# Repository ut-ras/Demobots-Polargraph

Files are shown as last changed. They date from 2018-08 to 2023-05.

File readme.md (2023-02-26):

# Demobots Polargraph
Polargraph GIF

Automated art robot originally built by the 2018-2019 Demobots committee, Revived and Documented by Jake (Demobots) in Spring of 2023

Polargraph translates digital art to a larger, more tangible medium. 

# Table of contents
  - [Demonstration Instructions](#demonstration-instructions)
  - [Updates](#update---feb-26th-2023)
  - [Installation](#installation-via-arduino-ide)
  - [Software](#software)
  - [Electrical](#electrical)
  - [Current Contributors](#current-contributors)

## Demonstration Instructions
### [For current demonstration instructions, click here!](Demos/readme.md)

## Update - Feb 26th, 2023 

- 2023 revival release can be found [here!](https://github.com/ut-ras/Demobots-Polargraph/releases)
- We now have a whiteboard attached to polargraph for easier demos.
- There are now very comprehensive demo instructions, see above.
- There should now be *way* more documentation throughout as well. 

## Installation Via Arduino IDE

1. Download and install the latest version of the Arduino IDE from the official website. Install the [AccelStepper](https://www.airspayce.com/mikem/arduino/AccelStepper/index.html) library via the Arduino IDE Library Manager.

2. Grab the latest release of Polargraph's code and documentation from [here](https://github.com/ut-ras/Demobots-Polargraph/releases) or clone the repo.

3. Open the Arduino IDE, click on File > Preferences, and in the "Additional Boards Manager URLs" field, add this URL: 

```https://dl.espressif.com/dl/package_esp32_index.json```

4. Go to Tools > Board > Boards Manager, search for "ESP32", and install the "ESP32 by Espressif Systems" board.

5. Connect the ESP32 board to your computer via USB.

6. Go to Tools > Board and select "ESP32 Dev Module" from the dropdown menu.

7. Select the appropriate port by going to Tools > Port and choosing the port that your ESP32 board is connected to.

8. Locate the `PolargraphESP32` folder from the release, and open `PolargraphESP32.ino` in Arduino IDE.

9. Click > Upload, and wait for the code to compile.

10. After it compiles, quickly move to ESP32 Board and hold down the `BOOT` button. Hold it down until you see on the IDE that uploading has begun.

11. Wait for the upload to complete, and then install the ESP32-PICO-KIT into Polargraph, and draw away!

## Software

(Both require the [AccelStepper](https://www.airspayce.com/mikem/arduino/AccelStepper/index.html) library)

### [PolargraphESP32](PolargraphESP32) (In use, not maintained)
Runs on an ESP32 in FreeRTOS. Hosts a web server and control interface on the device, and can either connect to an access point or deploy one. Allows users to upload SVG drawing for robot to draw.

### {DEPRECATED} PolargraphArduinoGIOT 
The deprecated PolargraphArduinoGIOT version is included [here](DEPRECATED_FILES/PolargraphArduinoGIOT), but hasn't been touched since 2019, feel free to look into it. 
Runs on an ESP8266. Uses Google Cloud IOT device manager for communication, and connects to an AppEngine web server in polargraph_appengine.

## Electrical
 * [ESP32-PICO-KIT V4 / V4.1](https://docs.espressif.com/projects/esp-idf/en/latest/esp32/hw-reference/esp32/get-started-pico-kit.html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)
 * 2x [NEMA 17 2A Stepper Motors](https://www.amazon.com/Stepper-Bipolar-4-lead-Connector-Printer/dp/B00PNEQKC0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)
 * 2x [A4988 Pololu Stepper Drivers](https://www.pololu.com/product/1182)
 * [5V, 5A Step-Down Voltage Regulator D24V50F5](https://www.pololu.com/product/2851)
 * 12V, 24-36W DC Power Supply
 * 100uF, 50V Capacitor
 * Breadboard with Jumpers

### Circuit Diagram 

Still need to put one here...
*WIP*

### Breadboard Diagram
Note that the MS1 and MS2 pins of each A4988 Stepper Driver are both 5V high, this sets the stepper motors to eighth step, refer to the [A4988 pinout](Electrical/A4988_pinout.png) as needed.

The exact order of the stepper driver output wires depends on the stepper motor used, refer to the [A4988 pinout](Electrical/A4988_pinout.png) as needed.
</br>

![connections](Electrical/breadboard_diagram.png)

*An ESP32-PICO-KIT Fritzing part doesn't exist as of writing, the other ESP32 board was used just to illustrate the pin connections.*

## Current Contributors
 - Jacob Tomczeszyn (Demobots Head) (4jakers18 on the RAS Discord server)

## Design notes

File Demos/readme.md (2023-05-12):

# Instructions for Demos
This guide will hopefully be able to cover everything you'd need to know for demos and SVG files, and will be updated as the project changes. Still, if you encounter any issues, don't hesitate to reach out to me on discord!
 
   -- *Jake (Demobots Head)* 

 - [Setup and Inspection](#setup-and-inspection)
   - [Breadboard Diagram](#breadboard-diagram)
   - [Optional - Changing Out Paper](#optional---changing-out-paper)
 - [Connecting](#connecting)
   - [SSID/password](#connect-to-the-esp32s-access-point-using)
 - [Drawing](#drawing)
   - [Points](#points)
   - [Vector Drawings](#uploading-vector-files-drawings)
 - [SVG Files](#svg-files)
   - [Working SVG Files](#working-svg-files)

## Setup and Inspection
In it's current state, Polargraph is a little heavy and very unwieldy and cumbersome to move around, so be careful and ask for help if you need it. Be sure to grab it's wooden laser-cut stand (better one coming in the future) from the RAS Office as well.

After you've propped it up securely, verify that the winches (black wheels attached the motors) don't have any of their tension string tangled around them. Unravel the power supply cord from Polargraph and set aside. 

Unscrew the backplate of the electrical harness to access the breadboard. (It may be off already)

**Verify that there are no loose connections and that** **everything is seated properly in the breadboard(s).** 

**When doing this, refer to the circuit diagrams, breadboard diagram, pinouts, etc.**

### Breadboard Diagram
Note that the MS1 and MS2 pins of each A4988 Stepper Driver are both 5V high, this sets the stepper motors to eighth step, refer to the [A4988 pinout](../Electrical/A4988_pinout.png) as needed.

The exact order of the stepper driver output wires depends on the stepper motor used, refer to the [A4988 pinout](../Electrical/A4988_pinout.png) as needed.
</br>

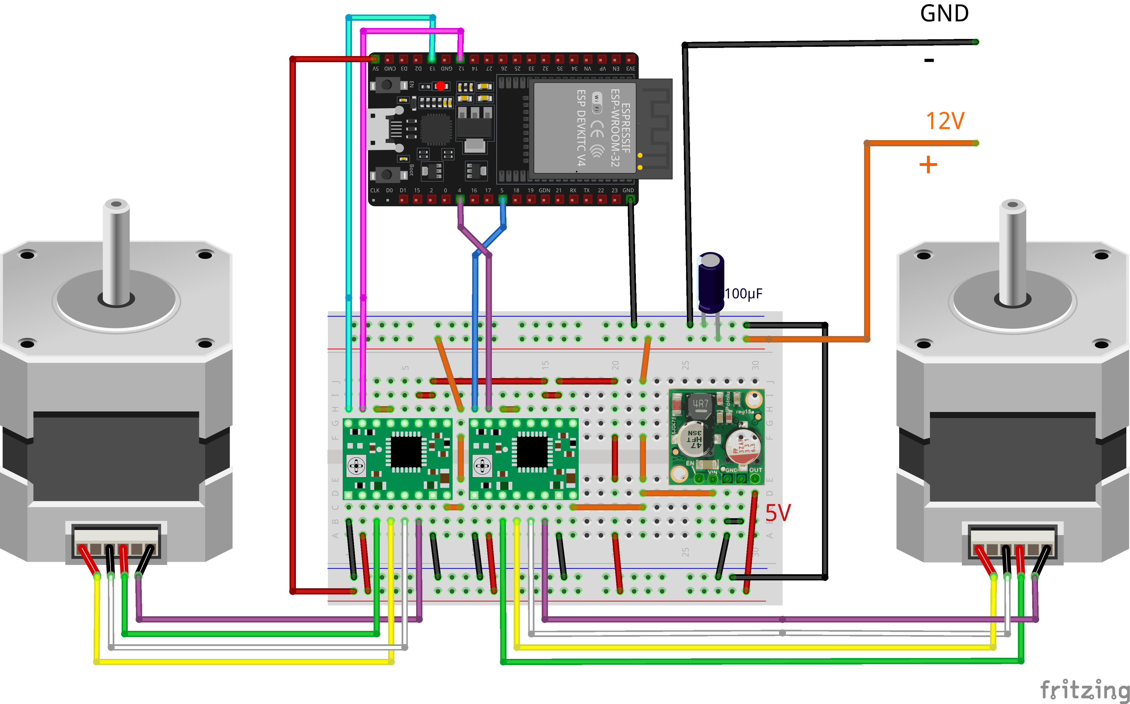
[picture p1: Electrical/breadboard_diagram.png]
connections


*Extra documentation can be found in [Electrical](../Electrical).*

Once you've double checked the connections, you can either rescrew the backplate or leave it open. Go ahead and plug in the power adapter to an AC wall outlet or extension cord.

You'll notice the ESP32's red light come on, along with a quiet but noticable noise coming from the stepper motors, if you don't, something is wrong. Unhook the tension wire from the paper clips and the top of the board, the motors should be locked, holding the gondola (marker holder) in place.

 *(Notice that when the Polargraph loses power, the steppers go limp and drop the gondola, we avoid that by placing the string of each winch hooked on the paper clip its next to.)*

 ## Optional - Changing Out Paper 
Get a piece/roll of large paper and cut it to your desired size, and either attach it to the board using the paperclips already on there, or by using tape. be sure to account for clearence with the winches when sizing your paper.

After you've attached the paper, either measure or guestimate the exact center of the page and mark it with a dot using the marker. There are guide arrows on the top and the left of the whiteboard that point to the center of the usable area.

Carefully and slowly, facing the board, manually adjust the winches (careful not to get anything tangled) such that the gondola's marker hole rest directly over the dot you marked. This is where we will tell Polargraph to set as the origin ("zero") of it's coordinate system. Double check that the gondola hole is exactly or as close as possible to the center.

Now place your marker ***(DRY ERASE ONLY)*** in the gondola, and secure it using the breadtie on there. the portion of marker sticking through the hole should be roughly the same length of the diameter of the castors on the gondola, the gondola should be resting on both the marker tip and the castors.

 ## Connecting
 On your device, be sure to have these instructions open/downloaded, as well as any SVG (Vector files) you'll want to upload to Polargraph to draw.

*The current Polargraph code can be finnicky about what SVG's it likes and which it doesn't like, so I've gone ahead and verified/prepared some good demonstration drawings:*

([Click here for working SVG files](#working-svg-files))

On your device's wifi settings, disable any automatic reconnection to the ***utexas*** wifi (or other public access points), this helps to avoid accidental disconnections.

### Connect to the ESP32's access point using:

|SSID| Password |
|--|--|
|Demobot  | demobot1234  |

**When you're connected to Polargraph's access point, you won't have internet access! Be sure to have everything you need before connecting.**

 ### Once connected, in your web browser, go to [192.168.4.1](http://192.168.4.1/)

 ## Drawing

You should see a page that looks like this:

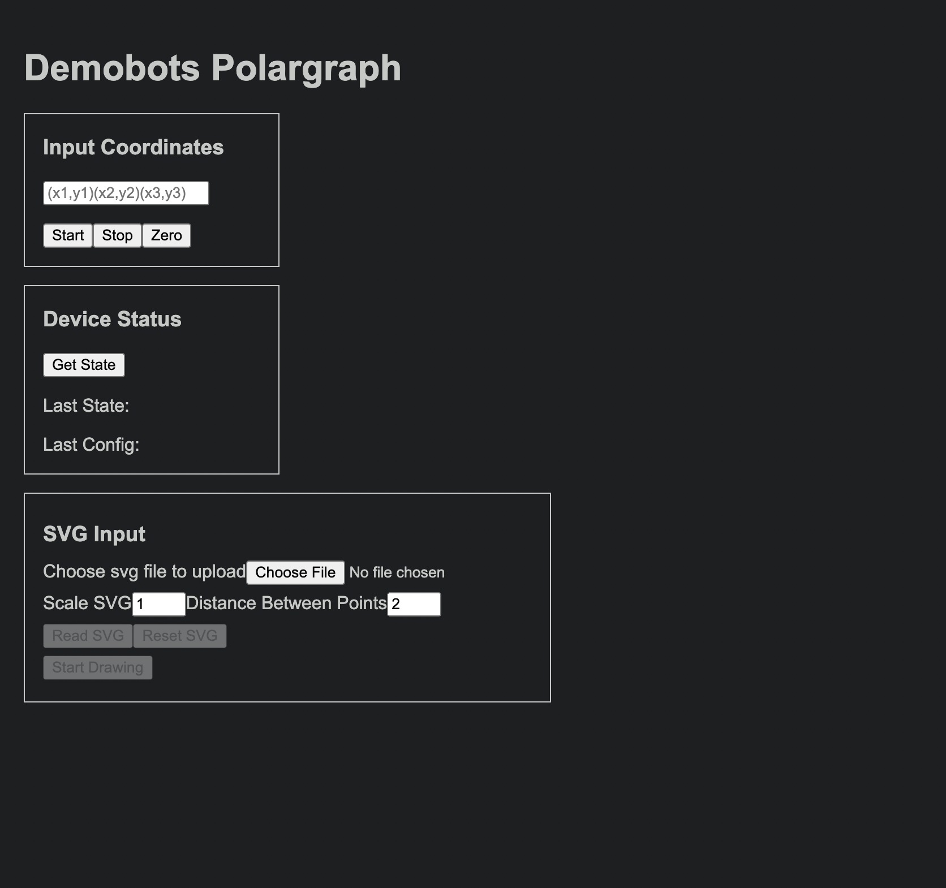
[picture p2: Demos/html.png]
HTML Page


Click on the button marked `Zero` to set the current position as the origin of the graph.

Get a feel for the limits of the board, as the current code is weird and inconsistent. As of 02/25/23, the whiteboard attached is 35" by 24", with a usable area about half an inch less due to the tape. There also appears to be some sort of coded change to the Y-Max set in [polargraph.h](../PolargraphESP32/src/polargraph/polargraph.h) that cuts it down a bit. All four of the limits seem to get cut down by 10mm regardless.

This all translates to the rough limits of:

|X-Max| X-Min |Y-Max| Y-Min |
|--|--|--|--|
| 440 mm  | -440 mm  | (~) 300 mm| -340 mm|

### Points

You can input `(x,y)` coordinates you want the gondola to travel to in the text box at the top.

Press `Start` to start a movement. 

Press `Stop` to pause a movement.

To cancel a movement in progress, you will have to press `Stop` and reboot the ESP32 (Do this via pulling it's `GND` Jumper to avoid the gondola falling).

You can chain together multiple points in sequence like this: `(x1,y1)(x2,y2)(x3,y3)` 

(Remember that drawing straight lines is hard to do manually, as this uses a Bipolar coordinate system for the movement, so it makes arcs when traveling between points.) 

To return to the origin, dont press `Zero`! This isn't a 3D Printer, it doesn't have any position feedback. 
Simply type `(0,0)` into the text box and press `Start`.

### Uploading Vector Files (Drawings)

Before connecting to Polargraph, download the SVG files found [here](SVGs/WORKING).

Click the `Choose File` button on the webpage, and select the SVG file you want to draw.

Scale the SVG if needed [(see below)](#svg-files) in the `Scale SVG` box. This is a multiplier for the default size of the file, numbers greater than `1.0` will increase the size, to decrease the size of the image, input the scale as a decimal less than `1.0`. For example: for a 175% scale, type: `1.75`, for a for a 35% scale, type: `0.35`. (Negative values will flip the drawing, try to avoid that).

Don't worry about the `Distance Between Points` box, changing this number can break things, leave at `2`.

After you've chosen your file and scaled to your heart's desire, click  the `Read` button. 

This loads the drawing path, scroll down to see the preview windows, the top is the SVG, the bottom is the drawing path that Polargraph will take.

Click `Start Drawing` to start drawing! (who would've guessed?)

When you're down with that drawing, or want to have something new on the board, click `Reset SVG` or refresh the page. 

***Don't*** click `Read SVG` while you already have a SVG loaded in. Having more than one at a time can result in bad paths. 

## SVG Files

The vector to movement algohrithm is complicated, and to be honest, I'm not sure which file here actually contains that code...

So I've had to work out the following by trial and error!

- Only certain SVG's will work properly, they have to consist of vector paths only with a thickness of one pixel.
- Don't use any "image to vector" converters online, its best to trace out the path of the drawing you want using Inkscape or a similar program.
- Some of the 'Working' SVG files are still too big/small to be drawn properly in the current configuration. Use them based on the notes below.

### Working SVG Files

SVG's confirmed to work can be found [here](SVGs/WORKING)
________________________________________________________
[longhorn](SVGs/WORKING/longhorn.svg)



- Best SVG we have so far
- Centered on origin well, but the drawing path starts at the tip of the right horn, so there will be an ugly travel line unless you tell it to move to that coordinate and erase the travel line before starting drawing. 
- It is fairly small by default, but not undrawable, you should be able to scale to 5ish at the most, experiment with it.
________________________________________________________
[creeper](SVGs/WORKING/creeper.svg)



- About the same as longhorn.svg in terms of sizing and centering, ugly travel path is smaller.
- ***aww man***
________________________________________________________
[Spiral](SVGs/WORKING/Spiral.svg)


- The centering is off by a lot, the whole spiral is drawn though, but (for some stupid reason I'm sure) the spiral is centered down and to the right when read into Polargraph.
- I wouldn't go above a 2x for this one, its fairly big as is.
________________________________________________________
[running-dog-silhouette](SVGs/WORKING/running-dog-silhouette.svg)



- ***May be too big by default***, I haven't tested it in since implementing the currect conifugrations, play around with it. 
- Gets squished/squashed weird sometimes
________________________________________________________

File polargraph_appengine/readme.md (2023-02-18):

#{Deprecated} Demobots Polargraph IOT
UT Austin's R.A.S. Demobots made an Arduino polargraph on an ESP8266, and this example adds a Google App Engine front end and communication through Cloud IoT Manager's HTTP bridge. </br>
</br>
Cloud IOT provides a simple and secure REST API (cloudiotdevice) for the device to post state and get config to the device manager. The device manager stores some of the most recent states and configs, and another API (cloudiot) can access the device manager. </br>
</br>
Google AppEngine is a platform for building webapps, it hosts webapp and gives you access to diagnostic tools. </br>
</br>
If you deploy the project to appengine instead of running the server locally, pay attention to Cloud's pricing and data quotas, there is a free trial but the credits will run out eventually.

Polargraph Image

## Google Cloud Tutorials
AppEngine Tutorial: Setting up gcloud development environment, python bookshelf app, Flask, Jinja, OAuth, CloudSQL</br>
https://cloud.google.com/python/getting-started/tutorial-app</br>
Cloud IoT How-To's: Config, state, HTTP bridge </br>
https://cloud.google.com/iot/docs/how-tos/getting-started</br>
Cloud IoT REST Reference: APIs for the HTTP device manager (cloudiot) HTTP bridge (cloudiotdevice)</br>
https://cloud.google.com/iot/docs/reference/rest/</br>
Cloud IoT Manager Example: Using python client library to connect to IoT device manager with cloudiot API</br>
https://github.com/GoogleCloudPlatform/python-docs-samples/tree/master/iot/api-client/manager</br>
Cloud IoT Core JWT Arduino library: Cloud IoT end device examples on Arduino, JWT, receiving config, updating state, sending telemetry to PubSub with cloudiotdevice API</br>
https://github.com/GoogleCloudPlatform/google-cloud-iot-arduino</br>

## Arduino Libraries
ESP8266WiFi</br>
Google Cloud IoT Core JWT</br>
AccelStepper</br>
rBase64</br>
QueueList</br>

## Google Cloud Services
Google App Engine (python with Flask, Jinja, SQLAlchemy)</br>
OAuth 2.0 </br>
Cloud SQL </br>
Cloud IoT Manager with HTTP bridge</br>

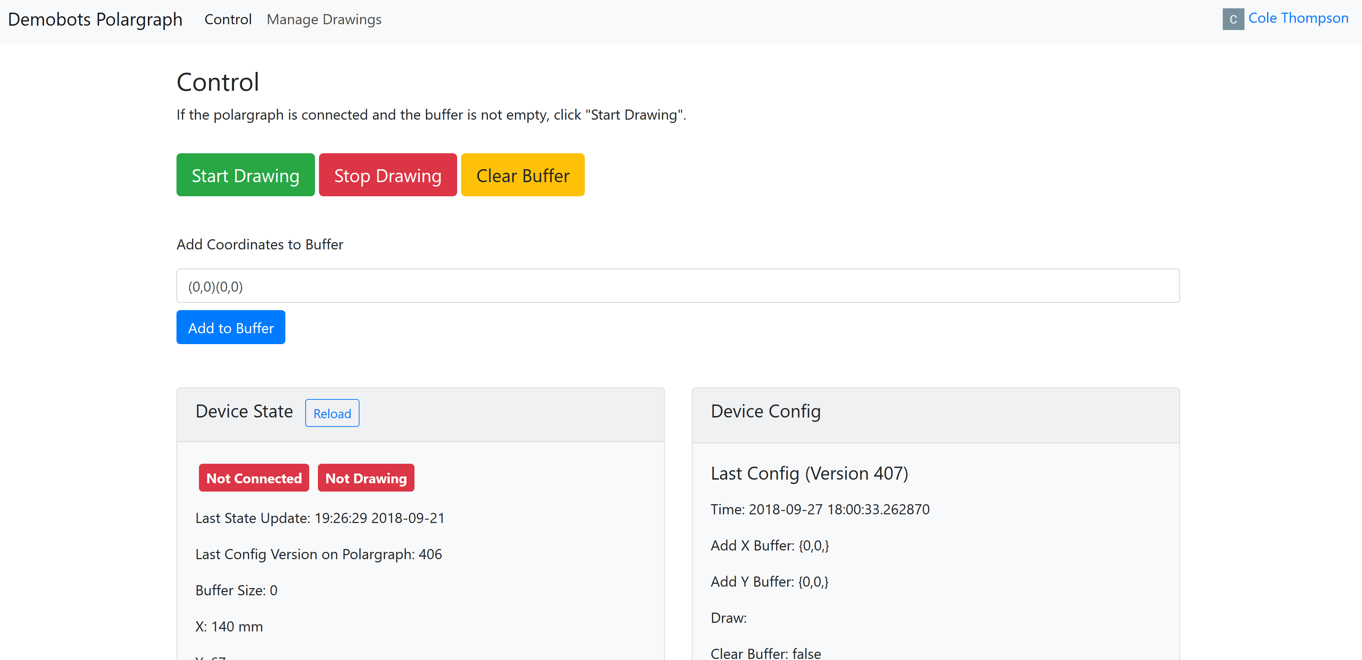
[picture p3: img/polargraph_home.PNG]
Polargraph Webapp Image

</br>
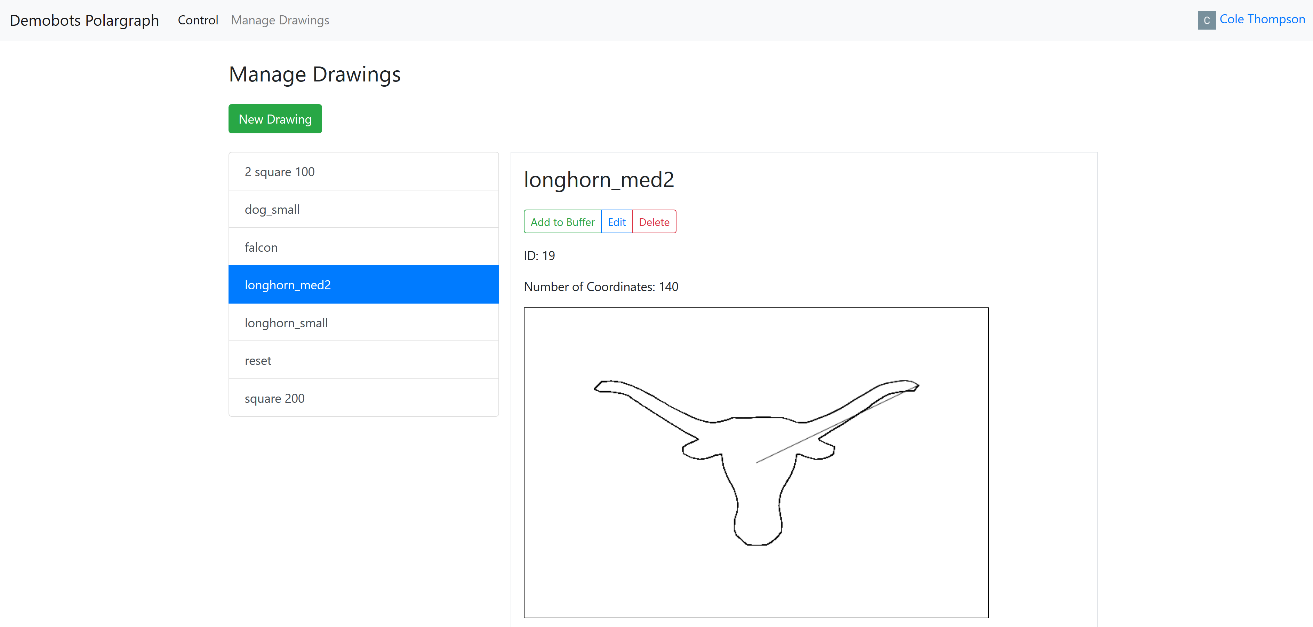
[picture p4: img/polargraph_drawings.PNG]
Polargraph Webapp Image


## Google Cloud Console Stuff to Set Up
Things to do when setting up this project. In general, follow the examples and tutorials.
* Google Cloud Project
* Cloud SQL Instance and drawings Database
* Cloud IOT Registry and Device with EC Public Private Key Pair and Service Account
* Enable all API's - Cloud IoT, AppEngine Flexible, Cloud SQL, CLoud SQL Admin, Google+, (might be more)
* Config files were not committed for security reasons, so make copies of everything with "\_EXAMPLE", remove the "\_EXAMPLE", and fill in your info, read comments for instructions

## Running AppEngine Locally (Linux)
First, make sure that project is set up like in Bookshelf tutorial, Google Cloud SDK is installed, and config.py/app.yaml are set up.</br>
virtualenv -p python3 env</br>
source env/bin/activate</br>
pip install -r requirements.txt</br>
python main.py</br>

## Running Cloud SQL Locally (Linux)
Install Proxy:</br>
wget https://dl.google.com/cloudsql/cloud_sql_proxy.linux.amd64 -O cloud_sql_proxy</br>
chmod +x cloud_sql_proxy</br>
Run Proxy:</br>
./cloud_sql_proxy -instances=project-name:us-central1:sql-name=tcp:3306</br>

## Hardware
 * [ESP8266 ESP 12-E WiFi Development Board](https://www.amazon.com/Makerfocus-ESP8266-ESP-12E-Internet-Development/dp/B01IK9GEQG)
 * 2x [NEMA 17 2A Stepper Motors](https://www.amazon.com/Stepper-Bipolar-4-lead-Connector-Printer/dp/B00PNEQKC0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)
 * 2x [A4988 Pololu Stepper Drivers](https://www.pololu.com/product/1182)

## TODO
Come to Demobots meetings or message R.A.S. if you want to participate! Any ideas are welcome. We are going to set up a more official task system in the future, but for now here are some tasks.

#### Arduino:
* Maybe use an RTOS to multithread
* Serial Mode (takes config as string)
* Minimize size and number of config transmissions for drawings

#### Cloud:
* Maybe using device metadata would be helpful for polargraph size, wifi connection settings, etc
* PubSub could be cool for drawings instead of using config
* Cloud IoT also has an MQTT bridge we can try

#### AppEngine:
* Editable canvas in Add Drawing
* Improve SVG tools to handle multiple paths
* SVG polargraph size text input
* Background thread or task queue when number of coordinates needs multiple configs

#### Hardware:
* New pen holder, possibly with a small servo to lift/place the pen
* Big reset / stop / motor power buttons (use interrupts for stop)
* Surface for drawing with dry erase markers
* Find an appropriate battery pack for outdoor demos

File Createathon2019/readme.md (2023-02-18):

# {Deprecated} Createathon Polargraph 2019
Large drawing machine for Createathon 2019. Includes a wireless device to lift and place the marker. Software based on the [UT Robotics and Automation Society Polargraph](https://github.com/ut-ras/Demobots-Polargraph-IOT/tree/master/PolargraphESP32). </br>

## Hardware
  * Polargraph
      * [ESP32 Pico Kit Microcontroller](https://www.mouser.com/ProductDetail/Espressif-Systems/ESP32-PICO-KIT?qs=MLItCLRbWsyoLrlknFRqcQ%3D%3D)
      * 2x [NEMA 17 2A Stepper Motors](https://www.amazon.com/Stepper-Bipolar-4-lead-Connector-Printer/dp/B00PNEQKC0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)
      * 2x [A4988 Pololu Stepper Drivers](https://www.pololu.com/product/1182)
      * Pololu 5V 5A Voltage Regulator
      * 12V DC input
  * Wireless Marker
      * ESP8266-01 Microcontroller
      * Servo Motor
      * Pololu 3.3V 2A Voltage Regulator
      * 5V rechargeable USB battery

### ESP32 Pins
Stepper | Step | Direction
--- | --- | ---
**R** | GPIO 12 |GPIO 13
**L** | GPIO 4 | GPIO 5

## Source Files

### PolargraphESP32_Async
  * `PolargraphESP32_Async.ino` main file, starts the FreeRTOS threads
  * `src/iot/` contains modules for WiFi and the HTTP Web Server
      * `src/iot/webserver.h` HTTP Web Server
      * `src/iot/webserver.cpp`
      * `src/iot/templates.h` Web Server front end HTML templates
      * `src/iot/iot_config.h` Quick WiFi settings
      * `src/iot/wifi_setup.h` WiFi connection functions
      * `src/iot/json_parse.h` JSON parse functions
  * `src/polargraph/` contains the polargraph device class, motor control, and the coordinate buffer
      * `src/polargraph/polargraph.h`
      * `src/polargraph/polargraph.cpp`
  * `static/` HTML and JS source files used to generate the string literals in the web server templates

### PolargraphMarker
  * `PolargraphMarker.ino` main file
  * `http.h` HTTP Client for Server-Sent Events
  * `http.cpp`
  * `marker.h` Servo code
  * `marker.cpp`

## Arduino Libraries
ESP32-Arduino, FreeRTOS (add the ESP32 to the Arduino board manager, select ESP32 Pico Kit) </br>
ESPAsyncWebServer (add as a zip)</br>
AsyncTCP (add as a zip)</br>
AccelStepper (Arduino library manager)</br>

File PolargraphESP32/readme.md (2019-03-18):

# Demobots Polargraph ESP32
Uses arduino-esp32 FreeRTOS core. Hosts a web server which allows nearby users to control the device when in the same local network. Supports SVG file inputs and lists of coordinates. </br>

Polargraph Image

## Arduino Libraries
ESP32-Arduino, FreeRTOS</br>
AccelStepper</br>

## Source Files
  * `src/iot` contains modules for WiFi and the HTTP Web Server
    * `src/iot/webserver.h` HTTP Web Server
    * `src/iot/webserver.cpp`
    * `src/iot/templates.h` Web Server front end HTML templates
    * `src/iot/iot_config.h` Quick WiFi settings
    * `src/iot/wifi_setup.h` WiFi connection functions
    * `src/iot/json_parse.h` JSON parse functions
  * `src/polargraph` contains the polargraph device class, motor control, and the coordinate buffer
    * `src/polargraph/polargraph.h`
    * `src/polargraph/polargraph.cpp`
  * `static` HTML and JS source files used to generate the string literals in the web server templates

## WiFi Settings
 * WiFi ssid, pass, and mode set in `src/iot/iot_config.h`
 * `WIFI_MODE` Modes:
   * `AP` Access Point: Device Broadcasts an access point, webserver IP default `192.168.4.1`
   * `STA` Station : Device connects to existing access point, webserver IP based on access point settings
   * `AUTO` Auto: Device searches for existing access point, and broadcasts if it can't find one

## Hardware
 * [ESP32 Pico Kit](https://www.mouser.com/ProductDetail/Espressif-Systems/ESP32-PICO-KIT?qs=MLItCLRbWsyoLrlknFRqcQ%3D%3D)
 * 2x [NEMA 17 2A Stepper Motors](https://www.amazon.com/Stepper-Bipolar-4-lead-Connector-Printer/dp/B00PNEQKC0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)
 * 2x [A4988 Pololu Stepper Drivers](https://www.pololu.com/product/1182)

### ESP32 Pins
Stepper | Step | Direction
--- | --- | ---
**R** | GPIO 12 |GPIO 13
**L** | GPIO 4 | GPIO 5

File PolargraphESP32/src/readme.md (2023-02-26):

# Polargraph Source Files
##### ***This readme was made using ChatGPT***

# [polargraph](/polargraph/)
The header file defines some constants: a `pos` struct to represent a position on the polargraph, and some functions to interact with the polargraph.

The constants defined are:

- `X_MAX` and `Y_MAX`: the maximum X and Y coordinates of the drawing area in millimeters.
- `STEP_MULT`: a factor to multiply the number of steps taken by the polargraph motors. This is used to increase the resolution of the polargraph drawing.
- `PULLEY_RADIUS`: the radius of the pulleys used by the polargraph in millimeters.
- `PULLEY_CIRC`: the circumference of the pulleys used by the polargraph in millimeters (calculated from `PULLEY_RADIUS`)
- `STEPS_PER_ROT`: the number of steps the polargraph motors take to complete one rotation.

The `pos` struct contains two 16-bit integers, `x` and `y`, to represent the X and Y coordinates of a position on the polargraph. It also defines an `operator=` function to assign one `pos` struct to another, an `operator==` function to compare two `pos` structs for equality, a `toString` function to convert a `pos` struct to a string, and an `toArray` function to convert a `pos` struct to an array of two 16-bit integers.

The public functions defined by polargraph.h and used in polargraph.cpp are:

- `setupPolargraph`:  This function initializes the polargraph by setting the max speed of each stepper motor, creating a queue to buffer incoming positions, and calculating the length of the strings based on the current position of the marker. It also prints some debug information to the serial console.
- `loopPolargraph`:This function is called repeatedly in the main loop of the program. It checks if the polargraph is currently drawing, and if so, it checks if it has reached the next position yet. If it has reached the position, it retrieves the next position from the queue and sets the polargraph to move to that position. If the queue is empty, it stops the drawing.
- `addToBuffer`: This function adds a new position to the end of the queue. It takes a pointer to a `pos` struct as an argument.
- `clearBuffer`: clears the buffer (clears the queue of positions).
- `getBufferSize`: gets the size of the polargraph buffer.
- `getCurrentPos`: gets the current position of the polargraph.
- `resetPos`: sets the current position of the polargraph as (0, 0) and enables drawing. No actual movement is done here, there are no limit switches or feedback.
- `getLeftLength`: This function calculates the length of the left string required to reach a given position pos_new.
- `getRightLength`: This function calculates the length of the right string required to reach a given position pos_new.
- `setPos`: This function sets the position of the marker to a given position pos_new. It first checks if the position is valid (i.e., within the boundaries of the drawing board). If it is valid, it calculates the new length of the left and right strings required to reach the new position. It then calculates the number of steps required for each motor to reach the new string lengths, and sets the motors to move to those positions. Finally, it updates the internal variables for the current position, string lengths, and number of steps.
- `getDistance`: calculates the distance between two `pos` structs.
- `getIsDrawing`: gets the current drawing state of the polargraph.
- `setIsDrawing`: sets the drawing state of the polargraph.

_________________________

# [iot](/iot/)

## wifi_setup.h

The `setupWiFiAutoScan()`, `setupWiFiAuto(`), and `setupWiFi()` functions are used to initialize the WiFi connection. `setupWiFiAutoScan()` scans for available WiFi networks, and if it finds the desired network, it connects to it as a Station (STA). If it doesn't find the network, it creates an Access Point (AP) and sets the IP address accordingly. `setupWiFiAuto()` does the same thing, but assumes that the WiFi mode is set to "AUTO". Finally, `setupWiFi()` is a more general function that allows the user to specify whether they want to use AP or STA mode.

The file also defines the local_IP, gateway, and subnet IP addresses, which are used to configure the static IP address of the Polargraph machine.
## iot_config.h
This file is a header for wifi_setup.h and defines the WiFi mode (`WIFI_MODE`) and the SSID and password for the WiFi network.

"AP" is currently set for access point mode.

## templates.h
This file contains html templates for [PolargraphESP32/static](../static)

## json.parse.h

This file contains a simple JSON parser.

### Functionality

The `getFromJson` function extracts a value from a JSON string given the attribute name. The function assumes that there are no duplicate names in the JSON string. The function finds values in the format `'attr_name':'val'` and returns `val`. 

The `getFromJson2` function is similar to `getFromJson`, but it returns a default value if the attribute is not found in the JSON string.

The `stringToBool` function converts a string value of either `"true"` or `"false"` to a boolean value.

### Future Improvements

The file contains a comment about potential improvements to the JSON parser. Specifically, the comment suggests using a thread with a char queue input to constantly stream chars from the queue and parse all JSON and coordinates into the polargraph input in one pass, just checking for the delimiters `{`, `:`, etc.

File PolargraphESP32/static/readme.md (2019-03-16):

# Templates

Develop front end pages here, escape the text (search online c++ escape tool) and add to `src/iot/templates.h`

## String Storage Examples
Some of the examples are untested, I'll test them at some point soon to make sure they are syntactically correct. </br>
</br>
Global buffer in SRAM initialized data.
```C++
#define HTML_LITERAL "<html><h1>Hello</h1></html>"
#define HTML_SIZE sizeof(HTML_LITERAL)
const char * html = HTML_LITERAL;
char * helloHTML() {
  return html;
}
```
Static buffer in SRAM initialized data.
```C++
#define HTML_LITERAL "<html><h1>Hello</h1></html>"
#define HTML_SIZE sizeof(HTML_LITERAL)
char * helloHTML() {
  static char * html_str = HTML_LITERAL;
  return html_str;
}
```
Static buffers in SRAM initialized data, using sprintf to add some run-time variables.
```C++
#define HTML_LITERAL "<html><h1>Hello %s</h1></html>"
#define HTML_SIZE sizeof(HTML_LITERAL)
#define BUFFER_SIZE (HTML_SIZE + 50)    //add room for max name length
char * helloHTML(char * name) {
  static char * html_str = HTML_LITERAL;
  static char buffer[BUFFER_SIZE];
  snprintf(buffer, BUFFER_SIZE, html_str, name);
  return buffer;
}
```
Three web pages stored in Flash buffers. If only one client is connecting, only one page needs to be loaded into one global buffer in SRAM data.
```C++
#include <pgmspace.h>
#define BUFFER_SIZE 100
char buffer[BUFFER_SIZE];   //stores 1 page at a time
const char fbuffer1[] PROGMEM = {"<html><h1>Hello 1</h1></html>"};
const char fbuffer2[] PROGMEM = {"<html><h1>Hello 2</h1></html>"};
const char fbuffer3[] PROGMEM = {"<html><h1>Hello 3</h1></html>"};
char * page1HTML() {    //put fbuffer1 in buffer
  int k;
  for (k = 0; k < strlen_P(fbuffer1); k++) {
    strcpy_P(&buffer[k], (char *)pgm_read_byte_near(fbuffer1 + k));
  }
  return buffer;
}
```
Avoid putting large constant strings on the stack or heap. </br>
</br>
https://www.geeksforgeeks.org/memory-layout-of-c-program/</br>
http://playground.arduino.cc/Learning/Memory</br>
https://learn.adafruit.com/memories-of-an-arduino/optimizing-sram</br>
https://www.arduino.cc/reference/en/language/variables/utilities/progmem/</br>

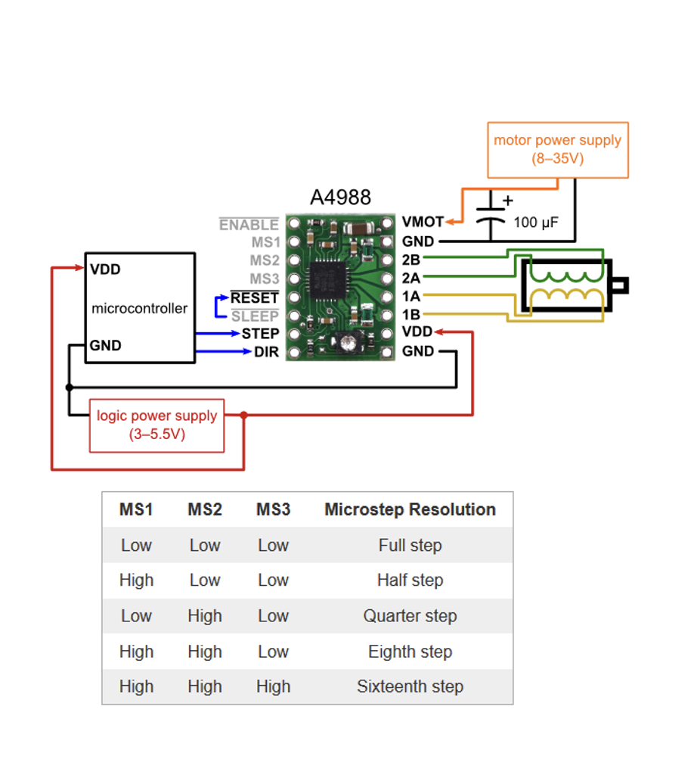
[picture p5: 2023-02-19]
Electrical/A4988_pinout.png

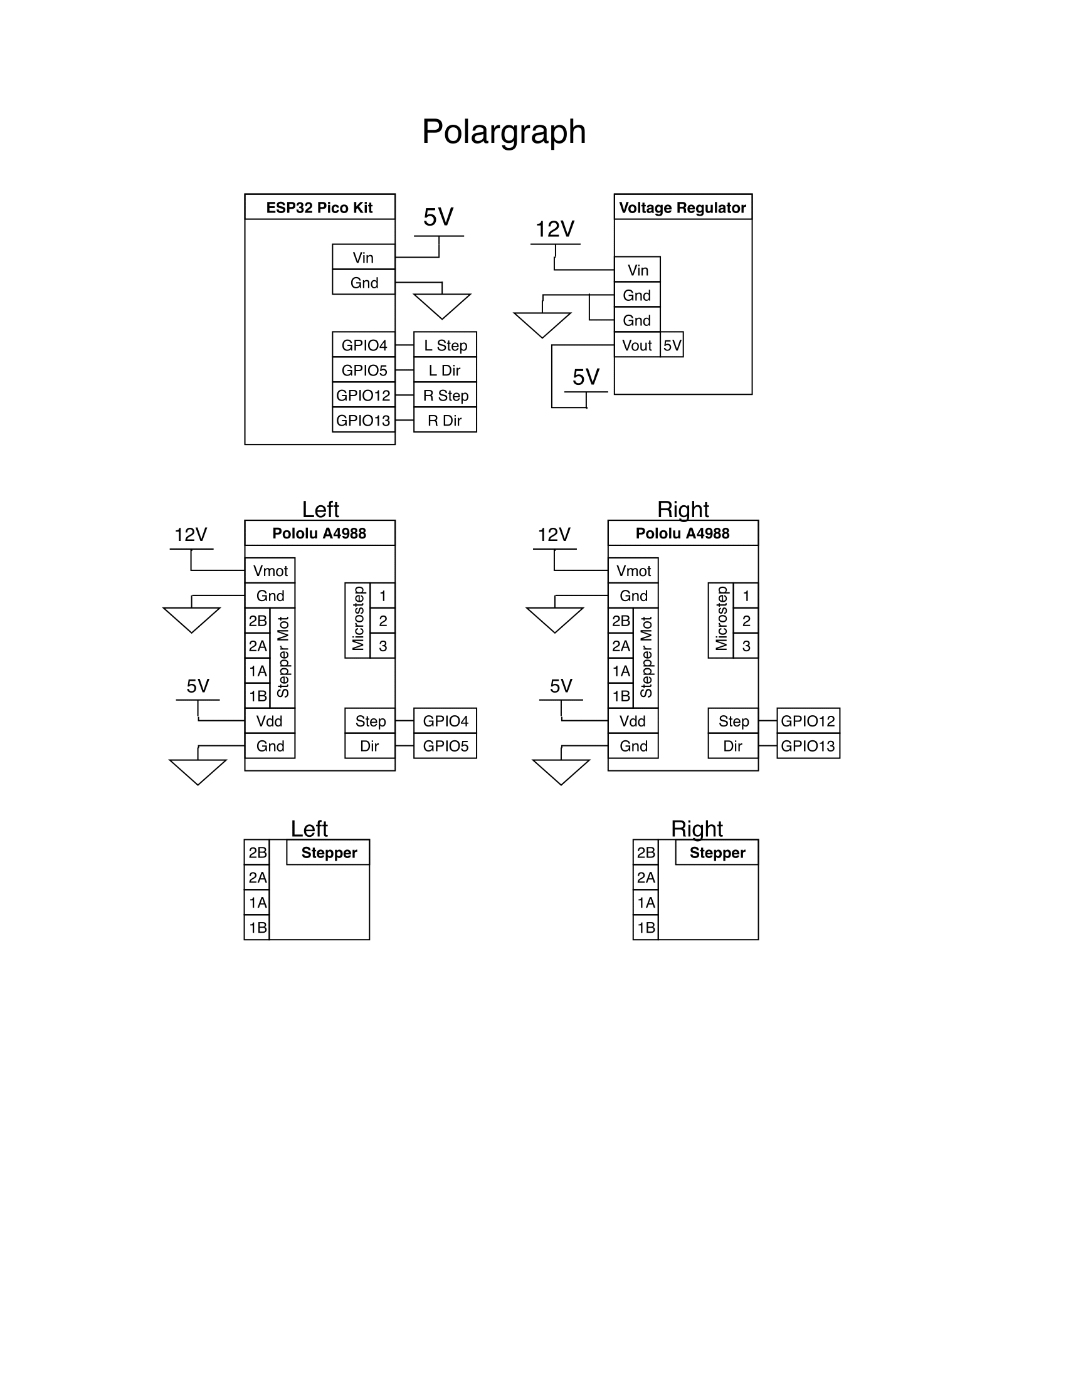
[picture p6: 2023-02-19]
img/connections-1.png

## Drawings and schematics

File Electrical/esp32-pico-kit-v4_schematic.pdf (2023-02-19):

Power Supply | ESP32 SIP

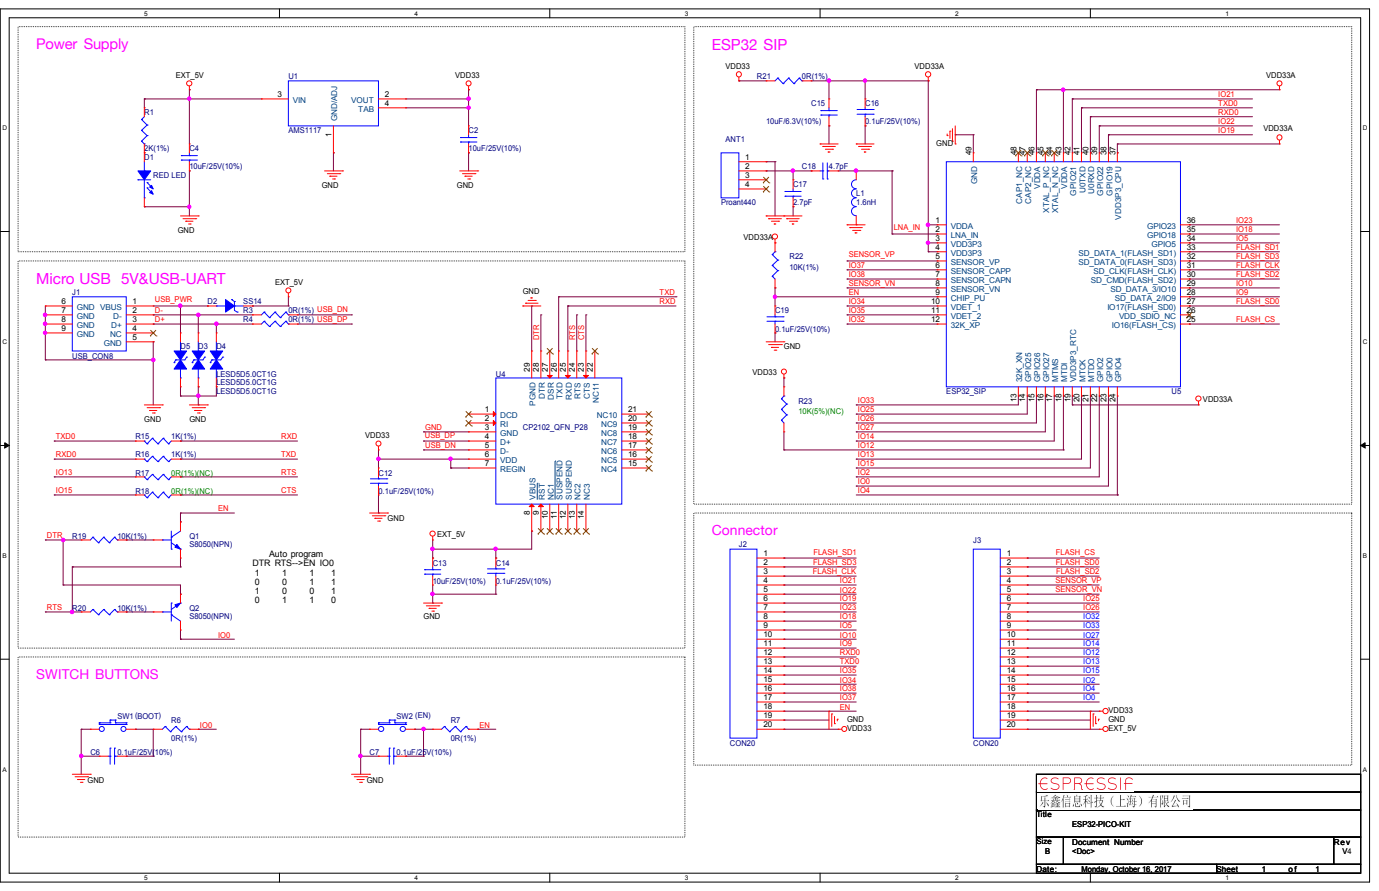
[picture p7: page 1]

Micro USB 5V&USB-UART

NC11 22 CTS 23 RTS 24 RXD 25 TXD 26 DSR 27 DTR 28 PGND 29

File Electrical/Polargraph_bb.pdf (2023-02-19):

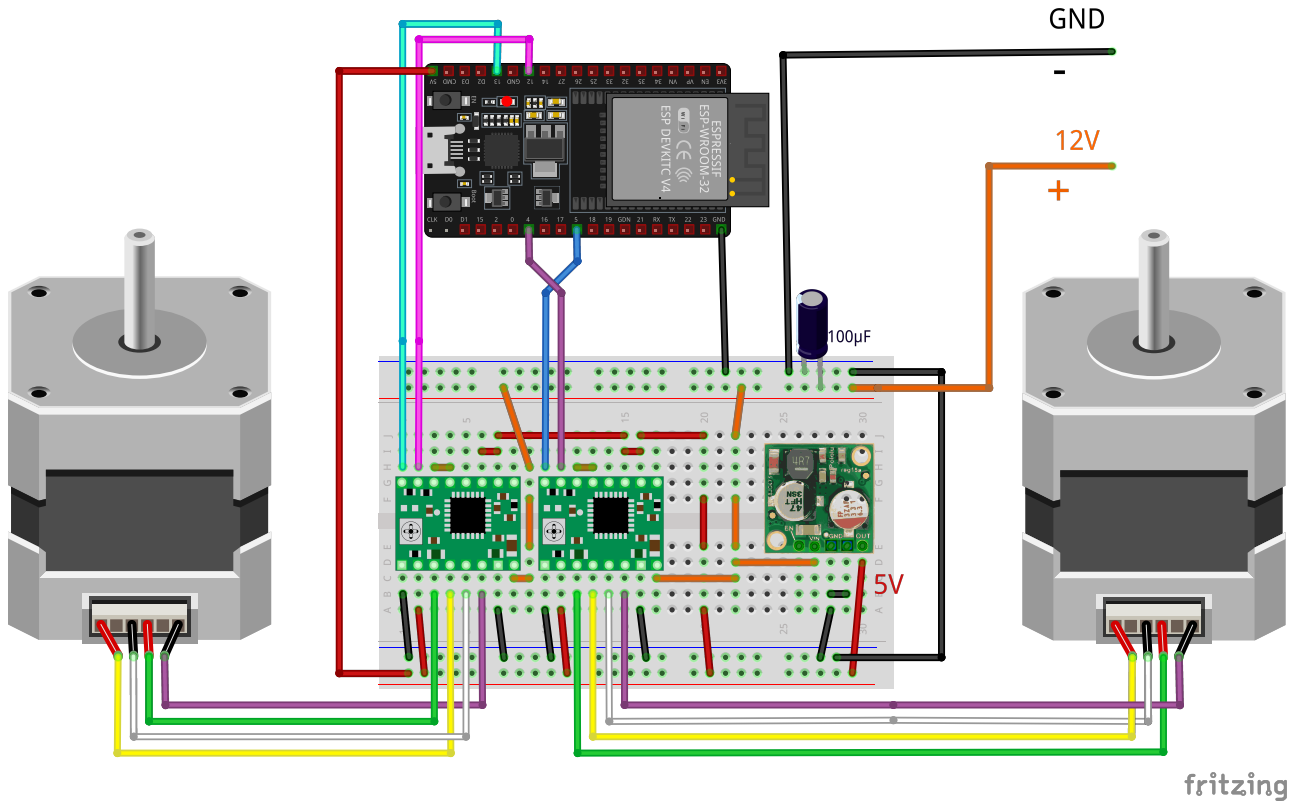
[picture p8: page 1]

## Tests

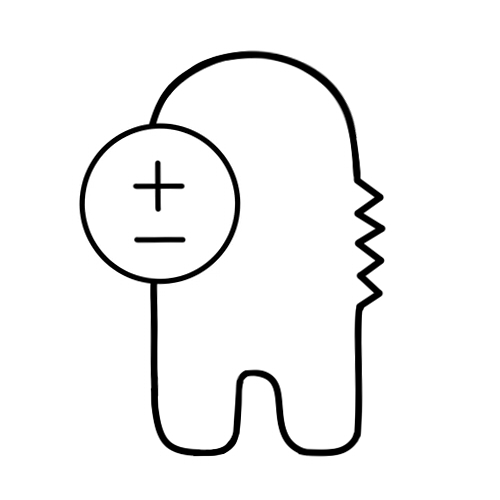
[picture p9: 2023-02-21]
Demos/SVGs/TESTING/vsus.jpg

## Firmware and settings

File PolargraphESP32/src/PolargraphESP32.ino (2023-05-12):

/*
 * UT R.A.S. Demobots IoT Polargraph
 *
 *
 * TODO
 * Improve front end
 *
 * Scheduler https://docs.espressif.com/projects/esp-idf/en/latest/api-guides/freertos-smp.html
 * Create Task https://docs.espressif.com/projects/esp-idf/en/latest/api-reference/system/freertos.html
 * Run Time stats https://www.freertos.org/a00021.html#vTaskGetRunTimeStats
 * Watchdog Timer https://docs.espressif.com/projects/esp-idf/en/latest/api-reference/system/wdts.html
 *
 * delay() wraps around the FreeRTOS vTaskDelay(), which implements blocking
 *    If you delay() a thread, the Scheduler will not give it a timeslice until
 *    its delay is up, so other threads are free to run.
 */

#include <Arduino.h>
#include <esp_task_wdt.h>

#include "/iot/webserver.h"
#include "/iot/wifi_setup.h"
#include "/polargraph/polargraph.h"


// Macro for printing debug information, quickly turn prints on/ off
#define DEBUG_MODE 0
#if DEBUG_MODE
  #define debugPrint(s) Serial.println(s)
#else
  #define debugPrint(s)
#endif


#define STACK_SIZE 2000     //words
#define PRI_POLARGRAPH 2
#define PRI_WEBSERVER 2


void setup() {
  Serial.begin(115200);

  setupWiFi("AP", ssid, pass);   //Access Point (AP), Station (STA), or Auto (AUTO)
  setupWebServer();                   //Set up the Web Server
  setupPolargraph();                  //Set up the Polargraph

  //debugPrint("WiFi mode=" + String(WIFI_MODE) + ", ssid = " + String(ssid) + ", pass = " + String(pass));
  //debugPrint("Web server at " + webServerPath);

  //start new threads for the polargraph and the webserver
  //The priority of the arduino main thread (setup/ loop) is 1
  xTaskCreatePinnedToCore(&vPolargraphTaskCode,"polargraphTask", STACK_SIZE, NULL, PRI_POLARGRAPH, NULL, 1);
  xTaskCreatePinnedToCore(&vWebserverTaskCode,"webserverTask", STACK_SIZE, NULL, PRI_WEBSERVER, NULL, 1);

  //remove the main arduino thread (setup/ loop)
  vTaskDelete(NULL);
}

void loop() {
  //this thread has been stopped in setup()
  /*
  debugPrint("loop start");
  delay(1000);
  debugPrint("loop end");
  delay(1000);
  */
}



void vPolargraphTaskCode(void * pvParameters){
  debugPrint("vPolargraphTaskCode start");
  while(true) {
    esp_task_wdt_reset();
    debugPrint("pg start");

    if (loopPolargraph()) {
      delay(500);
    }

    debugPrint("pg end");
  }
}

void vWebserverTaskCode(void * pvParameters){
  debugPrint("vWebserverTaskCode start");
  static long next_update = millis();

  while(true) {
    esp_task_wdt_reset();
    debugPrint("ws start");

    long t_curr = millis();
    if (t_curr > next_update) {
      loopWebServer();
      next_update = t_curr + MIN_UPDATE_MS;
    }else  {
      delay(20);
    }

    debugPrint("ws end");
  }
}


// Single thread old version
void singleThreadLoop() {
  //draw a line between two points if available/ enabled
  //returns true if at a good stopping point to check webserver
  static long next_update = millis();
  if (loopPolargraph()) {   //returns true if the polargraph is at a stopping point
    long t_curr = millis();
    if (t_curr > next_update) {
      loopWebServer();    //check the web server for updates
      next_update = t_curr + MIN_UPDATE_MS;
    }
  }
}

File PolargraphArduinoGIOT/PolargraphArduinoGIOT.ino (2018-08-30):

/*
 * UT R.A.S. Demobots IoT Polargraph
 */

#include <Arduino.h>
#include "src/iot/backoff.h"
#include "src/iot/esp8266_wifi.h"
#include "src/polargraph/polargraph.h"
#include "src/iot/json_parse.h"

#define UPDATE_MS 4000
#define CONFIG_TIMEOUT_MS (1000 * 8)

long next_update = 0;
String lastConfigTimestamp = "";
int last_conf = 0;   //get most recent

void setup() {
  // put your setup code here, to run once:
  Serial.begin(115200);
  setupWifi();
  pinMode(LED_BUILTIN, OUTPUT);
  setupPolargraph();
  next_update = millis();
}

void loop() {
  if (loopPolargraph()) {   //draw a line between two points if available/ enabled
    if (backoff() && (millis() > next_update)) {
      //sendTelemetry();
      updateStateConfig();
      next_update = millis() + UPDATE_MS;
    }
  }
}

void updateStateConfig() {
    String state = getState();
    Serial.println(String("state: ") + state);
    sendState(state);

    String conf = getConfig(CONFIG_TIMEOUT_MS, last_conf);
    Serial.println(String("config: " + conf));
    //Serial.println(String("config: " + conf.substring(0,74) + " ..."));
    updateConfig(conf);
}


String getState() {
  /* { 'x_position': 0,
     'y_position': 0,
     'left_length': 0,
     'right_length': 0,
     'drawing': true,
     'buffer_size': 0 }
  */
  String status = String ("{'x_pos': " + String(getCurrentPos().x) + ",");
  status += String("'y_pos': " + String(getCurrentPos().y) + ",");
  status += String("'left_len': " + String(getLeftLength()) + ",");
  status += String("'right_len': " + String(getRightLength()) + ",");
  status += String("'d': " + String(getIsDrawing()) + ",");
  status += String("'buffer_size': " + String(getBufferSize()) + ",");
  status += String("'last_conf': " + String(last_conf) + "");
  status += String("}");
  return status;
}


//TODO only update if its a recent timestamp
void updateConfig(String conf) {
  /* {'t':'0',
     'bx':'{}',
     'by':'{}',
     'd':'true',
     'cb':'false',}
  */
  if (conf != "" && conf.substring(0, 5) != "ERROR") {
    int index = conf.indexOf("{");
    if (index == -1) { return; }
    int new_conf = conf.substring(0, index).toInt();  //returns 0 if not an integer which should be ok because no config is 0
    Serial.println("new conf: " + String(new_conf) + " | last conf: " + String(last_conf));

    //Only update if its a new version
    if ((new_conf != 0) && (last_conf != new_conf)) {
      last_conf = new_conf;

      String requestedTimestamp = getFromJson(conf, "t", "-1");
      if (requestedTimestamp != "-1") {
        lastConfigTimestamp = requestedTimestamp;
      }

      boolean clear_buffer = stringToBool(getFromJson(conf, "cb", "false"));
      if (clear_buffer) {
        clearBuffer();
        setIsDrawing(false);
        //resetPos();
      }

      String buffer_add_x = getFromJson(conf, "bx");
      //delay(100);  //this is for serial buffer, can remove if not printing
      String buffer_add_y = getFromJson(conf, "by");

      boolean draw = stringToBool(getFromJson(conf, "d", "false"));
      setIsDrawing(draw);

      // Add coordinates to buffer
      if (buffer_add_x != "" && buffer_add_y != "" && buffer_add_x != "{}" && buffer_add_y != "{}") {
        int index_x = 1;
        int index_y = 1;
        int num = 0;

        Serial.println("Adding new coords to buffer");
        while (buffer_add_x.charAt(index_x) != '}' && buffer_add_y.charAt(index_y) != '}') {
          int next_index_x = buffer_add_x.indexOf(",", index_x);
          int next_x = buffer_add_x.substring(index_x, next_index_x).toInt();
          index_x = next_index_x + 1;

          int next_index_y = buffer_add_y.indexOf(",", index_y);
          int next_y =  buffer_add_y.substring(index_y, next_index_y).toInt();
          index_y = next_index_y + 1;

          pos new_pos = {next_x, next_y};
          addToBuffer(new_pos);

          num++;
          if (num % 5) { Serial.print("."); }
        }
        Serial.println("\nAdded new coords to buffer");
      }
    }
  }
  else {
    Serial.println("Conf not updated, " + conf);
  }
}

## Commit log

2018-08-30 IoT Example. Added a front end and HTTP device manager to the polargraph project using Google Cloud services. Also made some improvements to the polargraph line drawing.
2018-09-05 step multiplier for stepper driver microstepping
2019-02-23 ESP32 version for ut-ras demos, hosts the web server, simple text input
    In the future, moving toward using FreeRTOS threads and static buffers for string parsing to handle large numbers of coordinates. Also started working on the javascript svg parsing.
2019-02-23 FreeRTOS queue for the coord buffer, new WiFi init for demos, fixed coord parse bug
    Added some difficult SVGs so we can improve the parser. setupWiFiAuto function looks for an existing network, if it times out, it broadcasts an access point
    [PolargraphESP32.ino, polargraph.cpp, polargraph.h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]
2019-03-01 Threading code added to .ino
2019-04-06 first coordinate added to end of SVG to complete shape, fixed regex bug
    [polargraph.cpp, polargraph.h]
2023-02-19 added Fritzing and breadboard diagram
    [Polargraph.fzz]
2023-02-19 Uploading new a4988 pinout and moving files around
    [Polargraph.fzz]
2023-02-19 Update wifi_setup.h
    Moved setupWiFi earlier in header, fixed a compilation error in Arduino IDE
2023-02-21 Changed some SVGS, and board parameters in polargraph.h
2023-03-29 Reverted back to one src folder, removed lib folder
    [polargraph.cpp, polargraph.h, webserver.cpp]
